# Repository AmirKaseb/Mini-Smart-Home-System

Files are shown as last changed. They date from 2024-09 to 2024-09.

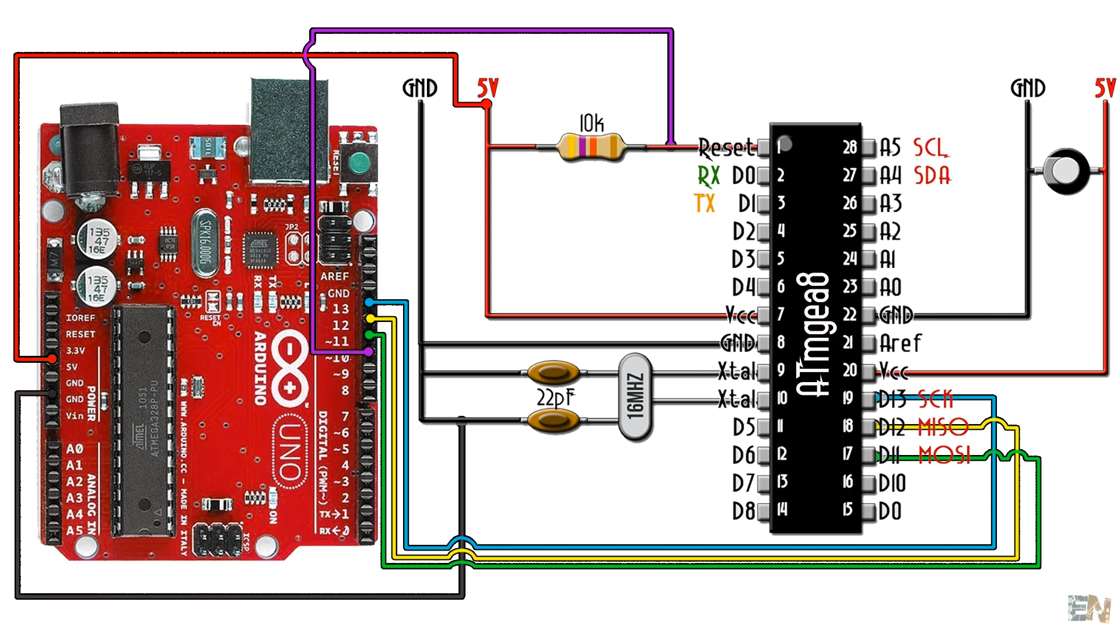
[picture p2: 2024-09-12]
Microcontroller & Hardware/Circuits/Arduino as ISP Programmer.png

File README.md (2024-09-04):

Computer Vision Part :-
=========================================================

This Part demonstrates real-time face recognition using OpenCV (`cv2`) and the `face_recognition` library in Python. The script captures video from the webcam, processes each frame to detect and recognize faces, and then displays the video with rectangles drawn around the recognized faces.

Requirements
------------

To install the required packages, run:

    cd /Computervision
    pip install -r requirements.txt

How to Use
----------

1.  **Place a Known Face Image:**
    *   Place an image file of the person you want to recognize (e.g., `amir.png`) in the same directory as the script.
2.  **Run the Script:**
    *   Use the following command to run the script:
    ````
        python face_recognition.py
    ````
3.  **How It Works:**
    *   The script will:
        *   Capture video from the default webcam.
        *   Load a known face from the provided image (`amir.png`).
        *   Detect faces in each video frame.
        *   Compare detected faces with the known face encoding.
        *   Draw a rectangle around recognized faces and display the name.
        *   Print a `Face Detected` flag to the console (`1` if a face is recognized, `0` otherwise).
4.  **Stop the Script:**
    *   Press the `q` key to stop the video capture and close all windows.

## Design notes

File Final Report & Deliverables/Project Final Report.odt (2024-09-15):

TEAM 11

Computer Vision Section:

Features:
- Beautiful and clear GUI implementation
- Clear and easy to use home layout that shows video, open door, lock door, add, delete and reset password buttons
- Dropdown menu for deleting persons from database instead of text field which is more convenient
- Confirmation dislogs for: open door, lock door, delete and reset password which gives homeowner a chance to think desicion through
- Notifications for carried out/cancelled activities which is convenient and less confusing for homeowner
- Most activities carried out using keys in the terminal, this allows running to be a lot smoother

Design considerations:
- Adding a person is a very simple process of snapping a picture of unknown person and creating a file with the persons image under the name of the person provided by the homeowner. This makes deleting a person exceptionally easy as all that needs to be done is delete the file's path obtained by joing the database path and the person's name.
- GUI is implemented using Flet which makes it easier to turn the program into a mobile app
-

Micro-controllers Section:

Features:

- Home Protection: When the house is locked, the PIR Sensor scans for motion and if detected, the ATmega sends a warning message to the Control Interface.
- Dynamic Lighting: When the light level of the surrounding is low, the Photo-resistor detects the low light and the ATmega lights up an LED and vice versa.
- Dynamic Fan Speed/RGB Indicator: According to the following ranges of temperature picked up by the NTC Thermo Sensor, the RGB – Fan Speed are as follow:
  ∗T > 30◦C : Red – 3500 RPM
  ∗ 30◦C => T => 20◦C: Green – [3000, 2000] RPM
  ∗ T < 20◦C: Blue – Fan Off
- Entering/Exiting House: A person can enter the house by:
  1- Entering the correct password on a 4*4 keypad
  2- By scanning their face (if a person is in the database, the Control Interface sends an open command to the ATmega)
  3- Pressing open on the Control Interface.
  A person can also lock the house via the Control Interface, turning off all the lighting and fan, and enabling the PIR Sensor to sends warning upon motion detection. The house/system is unlocked if the door is opened by any means of the 3.
- Door Password: A person can enter the house using a password and can change the password via the Control Interface. The password can have a length up to 31 characters. If a wrong password is entered, a Buzz is played and a warning message is sent to the Control Interface.

Libraries used:

- <Keypad.h>: For the keypad

Design considerations:

- If the door is opened, that means: the servo motor rotates up to a certain degree, waits for about 7 seconds and then closes.
- Added a “lock” feature, explained in the previous section.
- The fans always spin in 1 direction, therefore, the direction (in1 and in2) pins of the driver are connected directly to 5V and GND instead of the ATmega.

Other relevant information:

- The ATmega chip is programmed for the first time using an Arduino as ISP Programmer to burn the bootloader and/or upload the code.
- A USB to TTL (Serial) was used for the communication between the ATmega and the Control Interface (Computer), can also be used for uploading code after burning a bootloader first.

Hardware Section:

Altium:

Schematic:

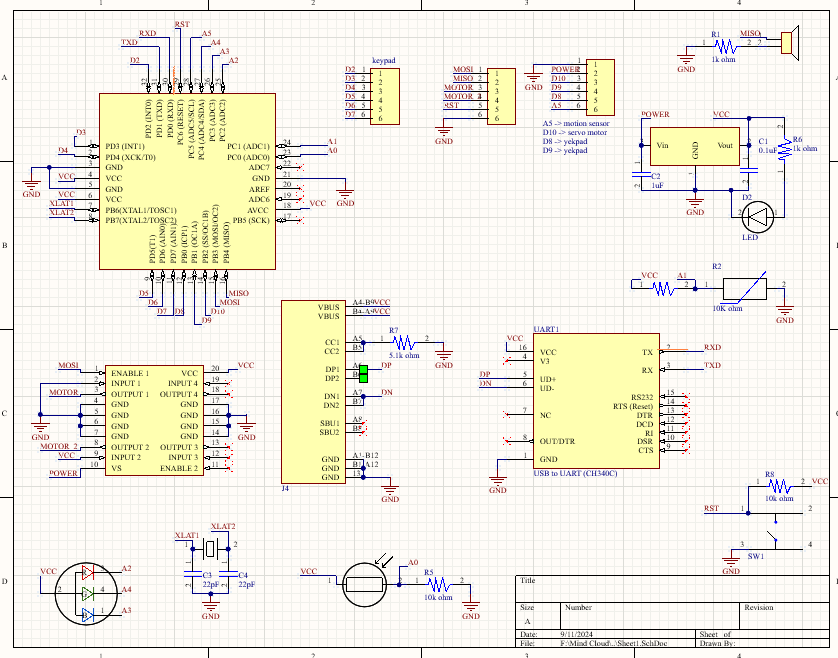
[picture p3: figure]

PCB-Top:

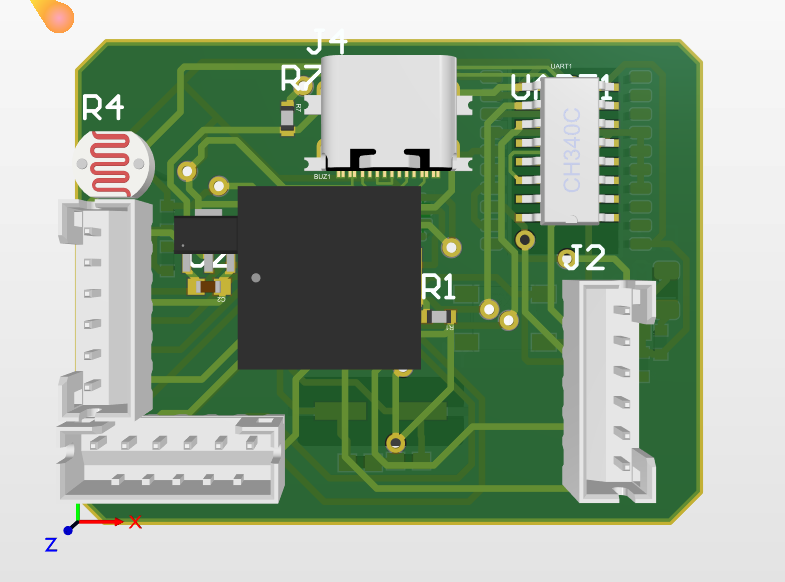
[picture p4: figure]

PCB-Bottom:

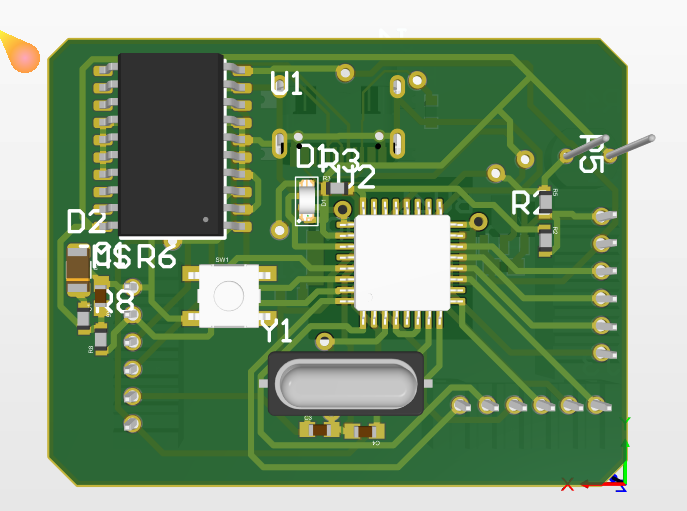
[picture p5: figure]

PCB-Traces:

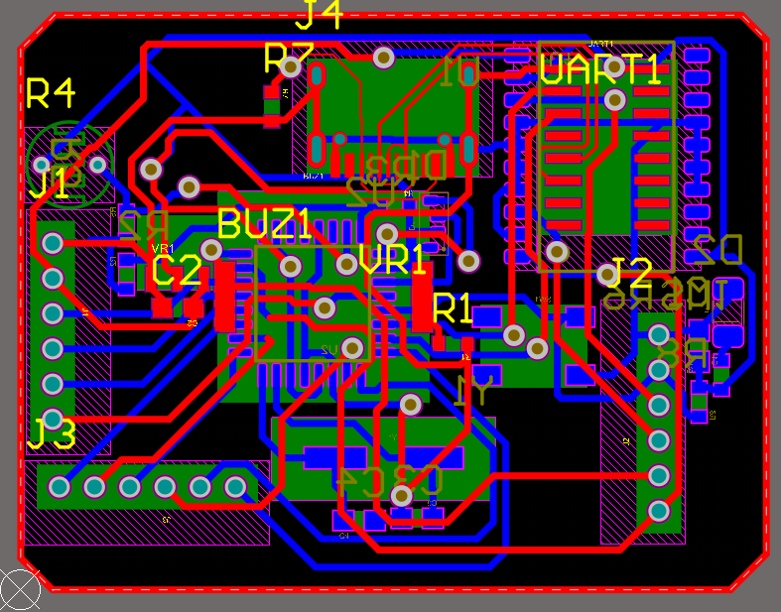
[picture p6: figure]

Design considerations:

- The servo motor, the fans motor and the keypad are not included in the Altium design, instead, they have pin-headers to connect them to the board externally.
- There are 6 Pins needed to exist as pin-headers to be able to program the ATmega chip (Burn the bootloader). The 6 pins are (MOSI – MISO – SCK – VCC – GND – Reset).
- We’re using a USB-to-UART chip and USB-C port for the communication of the ATmega and Computer.

Links:

AmirKaseb/Mini-Smart-Home-System: This Repo demonstrates our journey ( Team 11 ) for Mind Cloud Final Project (github.com) (https://github.com/AmirKaseb/Mini-Smart-Home-System/tree/main)

https://www.tinkercad.com/things/emIDLEaHkLq-mindcloud-megaproject-microcontroller-team-11

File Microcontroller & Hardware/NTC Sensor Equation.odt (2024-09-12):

NTC Thermistor Linearization

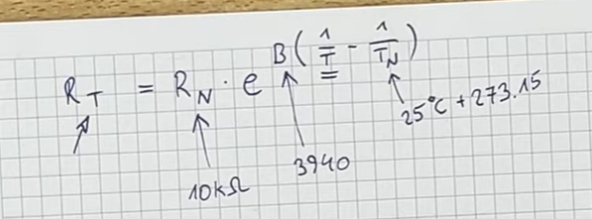
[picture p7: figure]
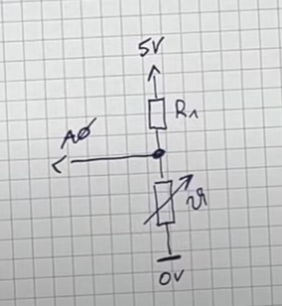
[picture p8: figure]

void loop(){

delay(1000);

double v_ntc = 5.0/1023 * analogRead(A0);

double current = (5.0-v_ntc)/10000.0;

double r_ntc = v_ntc/current;

double temp = 1 / ( log(r_ntc/10000.0)/3950 + 1/(25.0+273.15) ) -273.15;

}

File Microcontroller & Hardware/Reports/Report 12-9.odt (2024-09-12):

Days 9/9, 10/9, 11/9, 12/9

Computer Vision Section – Amir, Logy

Accomplishments:
Got started on gui and adding extra functions to the program

Problems encountered:
Choosing the most suitable gui to work with

Steps:
Read about different gui and comparing them according to activity, popularity and suitability.

Micro-controllers Section: - Badr

No new progress

Problems:

None

Hardware Section: - Mohammad Negm

- Mohammad worked and designed the whole system Schematic and PCB, the PCB is 2-sided to make it smaller.

- To consider: the 2 motors and the keypad are not in the design, instead, they’ve been allocated pinheaders to be connected externally, as it makes more sense this way.

Problems:

None

On 12/9, we’ve bought the necessary components, assembled and tested most of the system. Still CV to be tested.

Links:

AmirKaseb/Mini-Smart-Home-System: This Repo demonstrates our journey ( Team 11 ) for Mind Cloud Final Project (github.com) (https://github.com/AmirKaseb/Mini-Smart-Home-System/tree/main)

https://www.tinkercad.com/things/emIDLEaHkLq-mindcloud-megaproject-microcontroller-team-11

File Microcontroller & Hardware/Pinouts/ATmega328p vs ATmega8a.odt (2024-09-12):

Microcontroller – CV RELATION:

If the face recognized → open the door

Change password → change the password on the ardunio

Microcontroller: TinkerCad’s ATMEGA328P

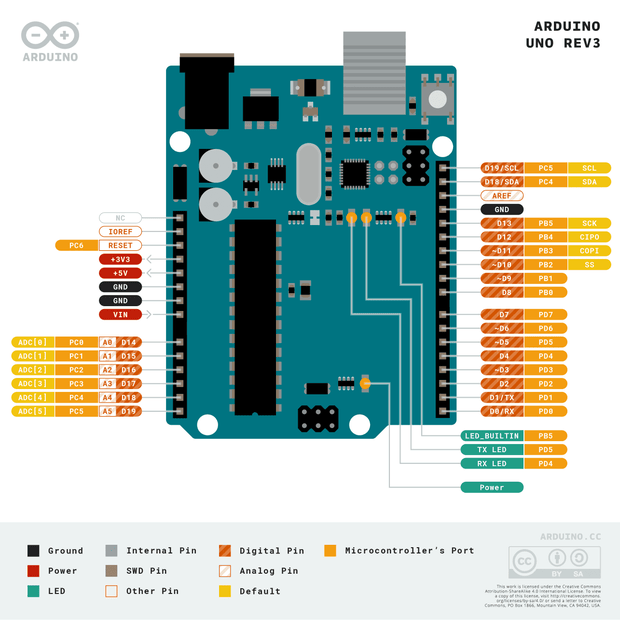
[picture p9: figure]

ATMEGA328P PDIP

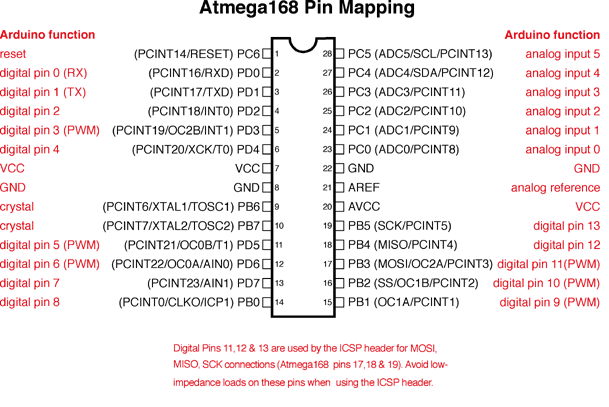
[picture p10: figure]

ATMEGA 8A PDIP

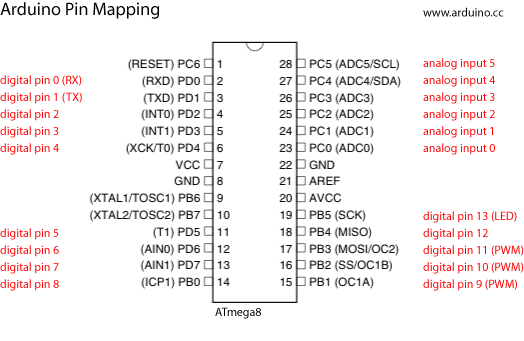
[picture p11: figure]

ATMEGA328P

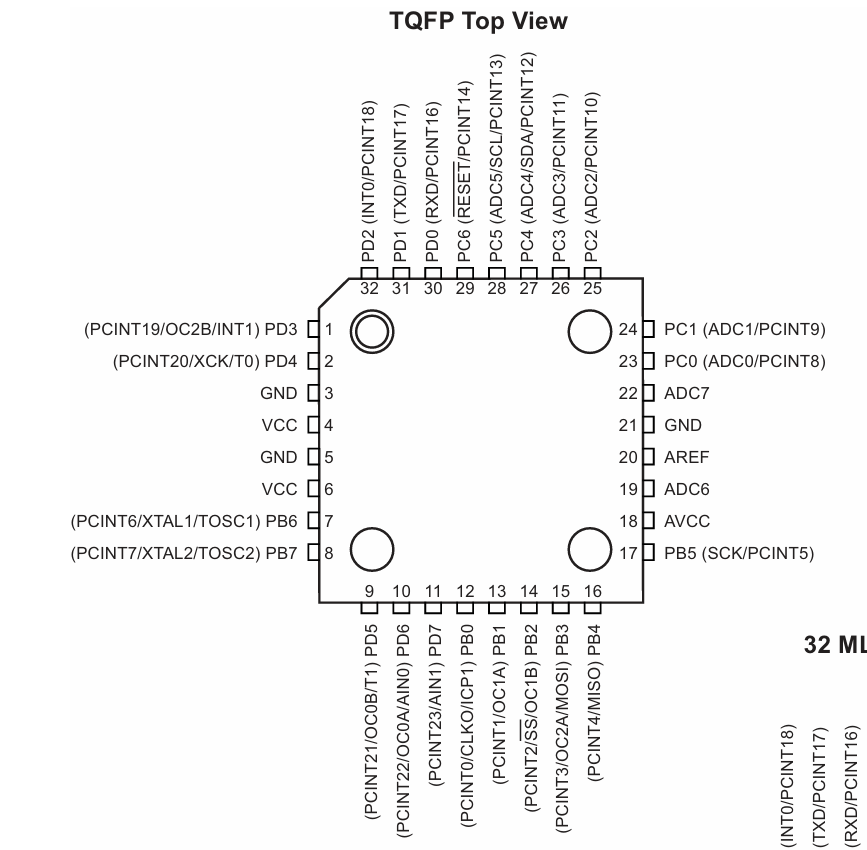
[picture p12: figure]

ATMEGA 8A

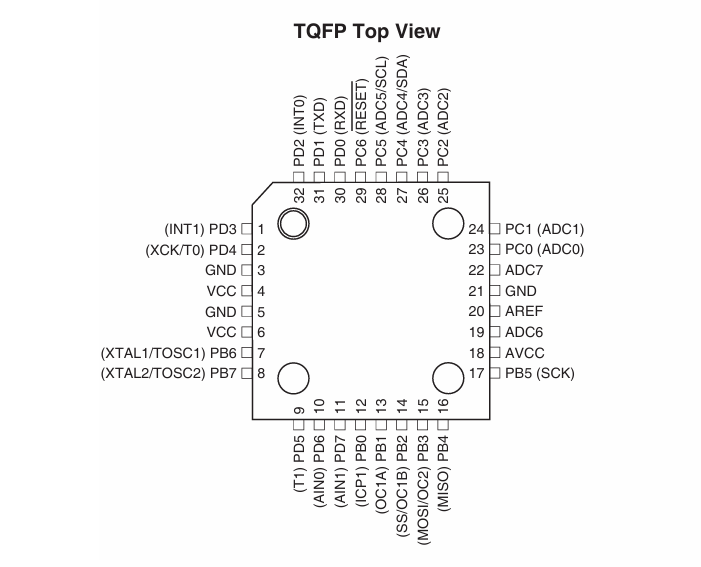
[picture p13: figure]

-ATMEGA328P Has 6 PWM channels while ATMEGA 8A only has 3 PWM channels

-Both has 6 ADC channels on PDIP package.

Components Links (Makers Store)

• Keypad : KeyPad 4×4 | Makers Electronics (https://makerselectronics.com/product/keypad-4x4)

• Buzzers : Magnetic Buzzer 5V 12mm 2 Pin | Makers Electronics (https://makerselectronics.com/product/magnetic-buzzer-5v-12mm-2-pin)

• Temperature sensor [NTC Thermistor Module] : NTC Thermistor 10KΩ | Makers Electronics (https://makerselectronics.com/product/ntc-thermistor-10kω)

• PIR sensor : PIR Sensor SR501 | Makers Electronics (https://makerselectronics.com/product/pir-sensor-sr501)

• LDR sensor : Photo Resistor Sensor LDR 7mm GL7528 8kΩ~20kΩ P=5mm | Makers Electronics (https://makerselectronics.com/product/photo-resistor-sensor-ldr-7mm-gl7528-8kω20kω-p5mm)

• RGB LED ; RGB Clear LED Common Cathode 5mm | Makers Electronics (https://makerselectronics.com/product/rgb-clear-led-common-cathode-5mm)

• Motor + Fan Blades : DC Motor R280 3-12V 13750RPM | Makers Electronics (https://makerselectronics.com/product/dc-motor-r280-3-12v-13750rpm) , Plastic Propeller 4 Blades 100mm | Makers Electronics (https://makerselectronics.com/product/plastic-propeller-4-blades-100mm)

• Driver L293D : L293D Quadruple Half-H Driver DIP-16 | Makers Electronics (https://makerselectronics.com/product/l293d-quadruple-half-h-driver-dip-16)

• LED (as lighting system) : Oval Red LED 3.8x5mm | Makers Electronics (https://makerselectronics.com/product/oval-red-led-3-8x5mm)

• Servo motor : Micro Servo SG90 0:180 Degree | Makers Electronics (https://makerselectronics.com/product/micro-servo-sg90-0180-degree)

Arduino

• ATMEGA 8A : ATMEGA8A-PU 8KB 2.7V~5.5V AVR 1KB 16MHz FLASH 23 DIP-28 AVR Microcontroller Unit | Makers Electronics (https://makerselectronics.com/product/atmega8a-pu-8kb-2-7v5-5v-avr-1kb-16mhz-flash-23-dip-28-avr-microcontroller-unit)

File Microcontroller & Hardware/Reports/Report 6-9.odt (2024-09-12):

Days 4/9, 5/9

Computer Vision Section – Amir, Logy

Accomplishments:
AI model that recognizes faces, successfully categorizes them into known and unknown by going through pictures of all known persons' faces in a database

Problems encountered:
None so far

Steps:
1. Training a model that recognizes faces using mainly face_recognition library, drawing frames around the face notifying the webcam's user whether they've been recognized or not
2. Writing a function that iterates over all pictures saved to a database to load images of known persons for the model to work with
3. Writing a function to extract names of persons from image's path for general ease (rather than turning to hard coding)
4. Work is readily uploaded to GitHub for ease of communication with teammates

Micro-controllers Section: - Badr

Looked into the specs and datasheet of the ATmega8A, found out that:

1- It’s a lower profile chip compared to the ATmega328P, with smaller memory and storage size. So, I have to keep the program size/memory consumption in consideration.

2- It has 3 PWM channels/pins and 6/8 ADC channels, depending on the package.

3- Has the same pinout as the ATmega328P on the Arduino Uno, so simulation on Tinkercad was somewhat possible and easy.

Learned how to work with the new stuff first, the Photoresistor, the NTC Sensor and the 4*4 Keypad, understood how they work and how to code for them.

Looked for real parts to be able to confirm the compatibility of my code.

Coded and simulated most -if not all- of the functions of the system. The communication between the Atmega and the Control Interface on the laptop can’t be tested virtually, so I used the Serial Monitor as input/output, such functions that are completed are as follow:

- If the door is opened (using password on keypad or serial input): Start the system

functions and unlock the house (PIR won’t try to detect if an intruder is present if the door is opened).

- Measure surrounding lighting level with LDR (control light system level) and if the reading from the LDR is low, meaning low light in the environment, turn the LED on, else, turn it off.

- Measure temperature with a temperature sensor and depending on that reading the result is

shown on RGB LED as follows:

∗ Red: T > 30◦C

∗ Green: 30◦C > T > 20◦C

∗ Blue: T < 20◦C

- The temperature sensor reading controls the speed of the motor with a fan extension with the

aid of an L293D chip, it has 3 modes, if T<20c then the fan is off, between 20c and 30c the fan is dynamic between 2000RPM and 3000RPM, and T > 30c the fan speed is constant at 3500RPM.

- Use a PIR sensor to detect if there is anyone inside the home if the door is locked and print on the serial monitor that there’s an intruder (only if the house is locked).

• If a WRONG password is entered:

- Buzzer rings for 500ms.

- Show warning messages on the serial monitor.

- Abilty to lock the system again via a serial monitor input, to shutdown the system (fan, lights and sensors) and the PIR sensor will begin working.

Problems:

1- Wrote the code for the NTC temp sensor but couldn’t test it as the temp sensor on Tinkercad is different, so right now, I use hardcoded values to simulate the values of the pin of the NTC temp sensor. It has no solution right now, only we wait til we build the project and see if it correctly works.

2- Instead of using 3 pins of the ATmega for the motor driver, I only used the Enable pin on the driver to control the speed (I can set it to 0 if I want the fan to stop), and the Input1-Input2 pins of the driver are always GND-5V, so the fan always spins in 1 direction (makes sense anyways).

3- Now, I’m going to optimize the code to be more memory efficient.

Hardware Section:

Work only started 6/9.

Links:

AmirKaseb/Mini-Smart-Home-System: This Repo demonstrates our journey ( Team 11 ) for Mind Cloud Final Project (github.com) (https://github.com/AmirKaseb/Mini-Smart-Home-System/tree/main)

https://www.tinkercad.com/things/emIDLEaHkLq-mindcloud-megaproject-microcontroller-team-11

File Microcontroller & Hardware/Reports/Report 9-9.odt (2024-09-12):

Days 6/9, 7/9, 8/9

Computer Vision Section – Amir, Logy

Accomplishments:
Code now successfully deletes known persons from database when prompted, opens the door when prompted and saves an unknown person to directory

Problems encountered:
Not adjusting to changes in directory after person has been added/removed
Unknown person's image being captured and saved with the frame still on their face

Steps:
1. Created a function to delete a person by deleting image's path from directory
2. Assigned keys for delete, reset password, add person, open door allowing homeowner to do so anytime
3. Capture a picture of person before adding the frame for picture to be saved without it
4. Reload all images in directory after adding/removing a person to stay up to date

Micro-controllers Section: - Badr

- Finished everything.

- Optimized a bit. I was using string type data for taking input from the serial channel (the control interface), but it was taking a lot of memory, so I switched to an array of char with fixed size as the buffer.

Problems:

None

Hardware Section: - Noran. Badr

-We started working on the libraries of the components (sch and footprint), and finished most of the components (only 4 components remaining, should be finished on 9/9).

Problems:

None

Links:

AmirKaseb/Mini-Smart-Home-System: This Repo demonstrates our journey ( Team 11 ) for Mind Cloud Final Project (github.com) (https://github.com/AmirKaseb/Mini-Smart-Home-System/tree/main)

https://www.tinkercad.com/things/emIDLEaHkLq-mindcloud-megaproject-microcontroller-team-11

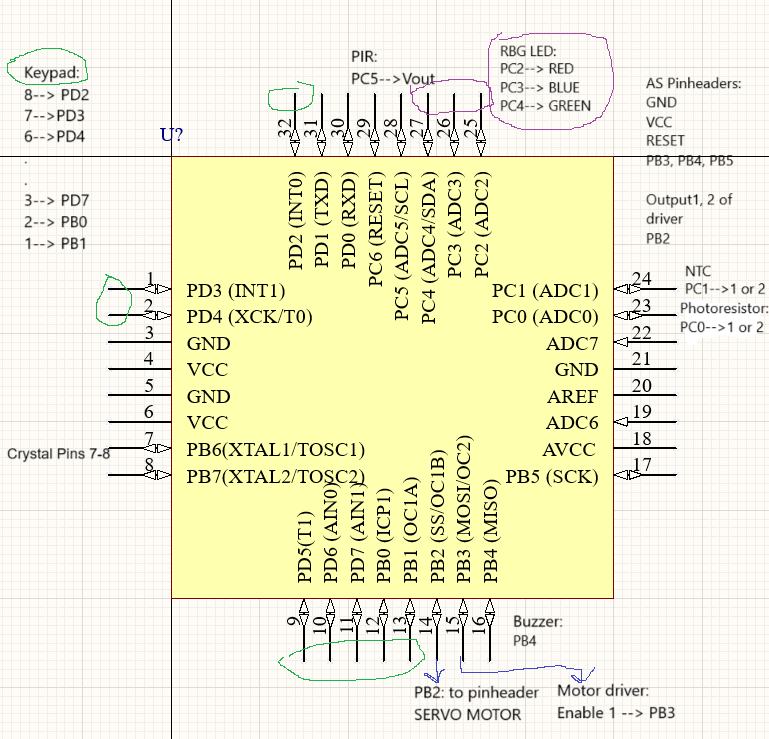
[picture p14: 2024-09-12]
Microcontroller & Hardware/Pinouts/ATmega8 TQFP Arduino-Pinout.png

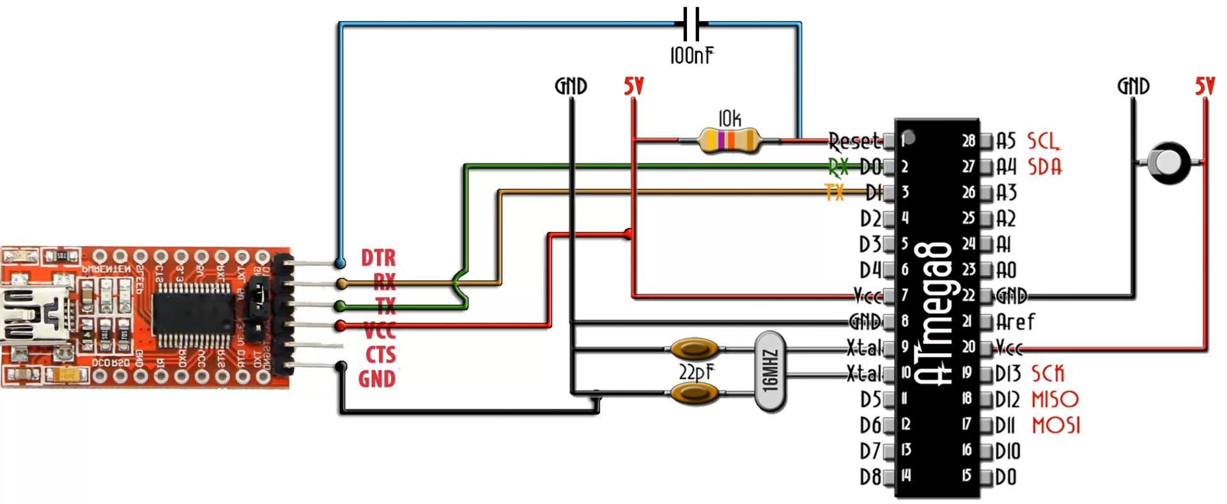
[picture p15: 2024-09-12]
Microcontroller & Hardware/Circuits/USB to TTL (Serial).png

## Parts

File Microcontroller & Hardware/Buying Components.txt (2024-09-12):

ATMEGA8A-PU 8KB 2.7V~5.5V AVR 1KB 16MHz FLASH 23 DIP-28 AVR Microcontroller Unit
KeyPad 4×4
Magnetic Buzzer 5V 12mm 2 Pin
NTC Thermistor 10K ±5% 3950K P=1.7mm (MF52A103J3950)
PIR Sensor SR501
Photo Resistor Sensor LDR 7mm GL7528 8kΩ~20kΩ P=5mm
RGB Clear LED Common Cathode 5mm
DC Motor R280 3-12V 13750RPM
Plastic Propeller 4 Blades 100mm
L293D Quadruple Half-H Driver DIP-16
Oval Red LED 3.8x5mm
Micro Servo SG90 0:180 Degree

Battery (9V?)

Resistors (220 - 1k - 10k - 5.1K)
Capacitors (22pF - 0.1uF - 1uF - 4.7uF - [10uF Electrolytic])

Crystal 16.000MHz
Push Button 4 pins and 2 pins

USB / UART : CH9102 Chip USB to TTL (Serial) Converter

Jumpers (Wires)

2 breadboards

Avometer

Arduino

~(Voltage Regulator - Diode)

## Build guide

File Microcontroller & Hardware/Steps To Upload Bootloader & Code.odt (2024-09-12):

Here's how you can set up your ATmega8A with a bootloader and then use it to upload code multiple times without needing an external Arduino:

### Step 1: Burn the Bootloader Using an External Arduino

1. **Set Up the Arduino as ISP**:

- Connect an Arduino (e.g., Arduino Uno) to your computer.

- Open the Arduino IDE.

- Load the "ArduinoISP" sketch from the examples (`File > Examples > ArduinoISP`).

- Upload this sketch to the Arduino. This turns the Arduino into an In-System Programmer (ISP).

2. **Connect the Arduino ISP to the ATmega8A**:

- Connect the Arduino to the ATmega8A as follows:

- **Arduino Pin 10** → **ATmega8A RESET (Pin 1)**

- **Arduino Pin 11** → **ATmega8A MOSI (Pin 17)**

- **Arduino Pin 12** → **ATmega8A MISO (Pin 18)**

- **Arduino Pin 13** → **ATmega8A SCK (Pin 19)**

- **Arduino GND** → **ATmega8A GND (Pin 8 or 22)**

- **Arduino 5V** → **ATmega8A VCC (Pin 7 or 20)**

3. **Burn the Bootloader**:

- In the Arduino IDE, go to `Tools > Board` and select "ATmega8" (with MiniCore installed, you'll see ATmega8 options).

- Set the clock frequency and other options according to your setup.

- In `Tools > Programmer`, select "Arduino as ISP."

- Click `Tools > Burn Bootloader`. This uploads the bootloader to your ATmega8A, making it ready for serial programming via the USB-to-TTL adapter.

### Step 2: Upload Code via USB-to-TTL Adapter

1. **Connect the USB-to-TTL Adapter**:

- Connect your USB-to-TTL adapter to the ATmega8A:

- **TX of the adapter** → **RX of the ATmega8A (Pin 2)**

- **RX of the adapter** → **TX of the ATmega8A (Pin 3)**

- **GND of the adapter** → **GND of the ATmega8A (Pin 8 or 22)**

- **VCC of the adapter** → **VCC of the ATmega8A (Pin 7 or 20)**

- **DTR or RTS of the adapter** (if available) → **RESET of the ATmega8A (Pin 1)** (through a 100nF capacitor).

2. **Upload Code**:

- Open the Arduino IDE.

- Write or open your code (sketch).

- Select the appropriate board (ATmega8 with the correct clock settings).

- In `Tools > Port`, select the COM port associated with your USB-to-TTL adapter.

- Click `Upload`. The bootloader will handle the process, allowing your code to be uploaded to the ATmega8A.

### Step 3: Repeat Code Uploads

- Now, each time you want to upload new code, you can directly use the USB-to-TTL adapter. The bootloader on the ATmega8A will automatically handle the code upload process, and there's no need to use the external Arduino again.

This setup allows you to easily and repeatedly upload code to your ATmega8A, making the development process more efficient.

If your USB-to-TTL adapter doesn’t have a DTR (Data Terminal Ready) pin, you can manually reset the ATmega8A to trigger the bootloader when uploading code. Here’s how you can do it using a button:

### Step 1: Wire the Button for Manual Reset

1. **Connect the Reset Pin**:

- Connect one leg of your push button to the **RESET** pin of the ATmega8A (Pin 1).

- Connect the other leg of the button to **GND**.

2. **Pull-up Resistor**:

- Connect a 10kΩ resistor between the **RESET** pin (Pin 1) and **VCC** (Pin 7 or 20). This pull-up resistor keeps the microcontroller running normally when the button is not pressed.

### Step 2: Manual Reset During Code Upload

1. **Prepare to Upload Code**:

- Write or open your code (sketch) in the Arduino IDE.

- Select the correct board settings (ATmega8 with the appropriate clock and bootloader).

- Select the correct COM port for your USB-to-TTL adapter.

2. **Trigger the Bootloader**:

- Click the **Upload** button in the Arduino IDE.

- Immediately after clicking **Upload**, press and hold the reset button on your ATmega8A.

- Release the button just as you see the "Uploading..." message in the Arduino IDE. This manual reset puts the ATmega8A into bootloader mode, ready to receive the new code.

3. **Code Upload**:

- The code should upload successfully if the timing of the reset is correct.

### Step 3: Repeat the Process

- Each time you upload new code, you’ll need to manually reset the ATmega8A at the right moment to trigger the bootloader.

This manual reset method is a common workaround when your USB-to-TTL adapter lacks a DTR pin. It may take a few tries to get the timing just right, but it works reliably once you get the hang of it.

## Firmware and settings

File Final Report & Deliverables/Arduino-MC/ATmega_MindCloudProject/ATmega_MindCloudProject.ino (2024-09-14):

#include <Keypad.h>

#define BUZZ 12
#define LED 13
#define motionPin A5
#define servoPin 10
#define LDRPin A0
#define TempPin A1
  
#define LED_R A2
#define LED_G A4
#define LED_B A3

#define EN 11
bool doorOpen=0;
bool sysUnlock=0;
  
void setup(){
  
  pinMode(BUZZ, OUTPUT);
  pinMode(LED, OUTPUT);
  pinMode(motionPin, INPUT);
  pinMode(servoPin, OUTPUT);
  pinMode(LDRPin, INPUT);
  
  pinMode(LED_R, OUTPUT);
  pinMode(LED_G, OUTPUT);
  pinMode(LED_B, OUTPUT);

  pinMode(EN, OUTPUT);
  
  Serial.begin(9600);
}

//Door/

void openDoor(int start=0){
  for (int i=start; i<=200; i++){ //turn the servo motor
    analogWrite(servoPin, i);
    delay(10);
  }  
}

void closeDoor(int end=200){
  for (int i=end; i>=0; i--){ //turn the servo motor
    //if (digitalRead(motionPin) == HIGH) return i; //if the door needs to open while it's closing, return with the value to start at opening
    analogWrite(servoPin, i);
    delay(10);
  }
  
  //return 60;
}


//KEYPAD Initials//
const byte ROWS = 4;
const byte COLS = 4;
char keys[ROWS][COLS] = {
  {'1','2','3','A'},
  {'4','5','6','B'},
  {'7','8','9','C'},
  {'*','0','#','D'}
};

//byte rowPins[ROWS] = {2, 3, 4, 5}; //connect to the row pinouts of the keypad
//byte colPins[COLS] = {6, 7, 8, 9}; //connect to the column pinouts of the keypad

byte rowPins[ROWS] = {9, 8, 7, 6}; //connect to the row pinouts of the keypad
byte colPins[COLS] = {5, 4, 3, 2}; //connect to the column pinouts of the keypad

Keypad keypad = Keypad( makeKeymap(keys), rowPins, colPins, ROWS, COLS );
int PW_Len = 6;
const int maxPW_Len = 32;
char Data[maxPW_Len]; //The incoming input password
char Master[maxPW_Len] = "123A45"; //The already set password
byte data_count = 0;
//bool CorrectPW;
//bool ChangePW;
////

//LDR//

void ldr(){

  const int threshold = 500;
  int sensor = analogRead(LDRPin);
  if(sensor<threshold){ //low light
    digitalWrite(LED,HIGH);  //turn LED on
  }  
  else{
    digitalWrite(LED,LOW);  //turn LED off
  }
}

//TEMP//
//NOTE: The temp doesn't work because tinkercad doesn't have NTC sensors.
// The code below is for NTC Sensor (replace 500 with the comment line)

float temp;

void tempSense(){
  
  float v_ntc = 5.0/1023 * analogRead(TempPin); //* 500;//
  float current = (5.0-v_ntc)/10000.0;
  float r_ntc = v_ntc/current;
  temp = 1 / ( log(r_ntc/10000.0)/3950 + 1/(25.0+273.15)  ) -273.15;
  //temp=80;
  Serial.print("Temp: ");
  Serial.print(temp);
  Serial.print("\n");
  //delay(1500);
  
  
}

//RGB Light//

void setLED(char c){
  
  if (c=='G') digitalWrite(LED_G, HIGH); 
  else digitalWrite(LED_G, LOW);
  if (c=='B') digitalWrite(LED_B, HIGH); 
  else digitalWrite(LED_B, LOW);
  if (c=='R') digitalWrite(LED_R, HIGH); 
  else digitalWrite(LED_R, LOW);

}

void RGB(float temp1){
  if (temp1<20){
  	setLED('B');
  }
  else if (temp1>=20 && temp1<=30){
  	setLED('G');
  }
  else {
  	setLED('R');
  }

}

//Motor Fan//

void motor(float temp1){
  
  //DC Motor R280 3-12V 13750RPM
  //analogWrite(EN, 255);
   
  if (temp1<20){
  	analogWrite(EN, 0);
  }
  else if (temp1>=20 && temp1<=30){
    int RMPtoAnalog = (temp*100/13750.0)*255;
  	analogWrite(EN, RMPtoAnalog);
  }
  else {
    int RMPtoAnalog = (3500/13750.0)*255;
  	analogWrite(EN, RMPtoAnalog);
  }
}

//System Functions//
void openCloseDoor(){
  startSys();
      
  sysUnlock=1;
  doorOpen=1;
  openDoor();
  delay(7000);
  closeDoor();
  doorOpen=0;
}

void startSys(){
  ldr();
  tempSense();
  RGB(temp);
  motor(temp);
}

//KEYPAD//
void kp(){
  
  delay(70);
  char key = keypad.getKey();
  
  if (key){
    Serial.print(key);
  	Serial.print("\n");
    Data[data_count]=key;
    data_count++;
  } 
  
  if (data_count==PW_Len){
  
    if(!strcmp(Data, Master)){
      Serial.print("Correct Password\n");
      Serial.print("Opening Door\n");
      openCloseDoor();
      
      delay(1000);
      }
    else{
      //
      //SEND To Control Interface Too//
      //
      Serial.print("Incorrect Password\n");
      tone(BUZZ, 300, 500);
      
      delay(1000);
      }
  
  	//Clearing the data array
    data_count=0;
    for (int i=0; i<PW_Len; i++){
      Data[i]=0;
    }
  }
  

}


//Control Interface//

void ctrl(){

  if (Serial.available() > 0) {
    char msg[32] = "";
    int len = Serial.readBytes(msg, sizeof(msg) - 1); //msg buffer
    msg[len] = '\0'; 

    if (strcmp(msg, "open") == 0 && !doorOpen) {
      Serial.print("Opening Door\n");
      openCloseDoor();
      
    } 
    else if (strcmp(msg, "change") == 0) {
        delay(5000);
        if (Serial.available() > 0) {
            len = Serial.readBytes(msg, sizeof(msg) - 1); 
            msg[len] = '\0'; 
            
            if (strlen(msg) <30) {
              strcpy(Master, msg); //Copy new password to Master
              PW_Len = strlen(msg);  
              Serial.print("Password Changed!\n");
            }
          else {
            Serial.print("Password Too Long!\n");
          }
        }
    }

    else if (strcmp(msg, "lock")==0) {
      sysUnlock=0;
      digitalWrite(LED,LOW);
      analogWrite(EN, 0);
      setLED('0');
      Serial.print("System Locked!\n");
    }
  
  }
  
}


//LOOP//

void loop(){
  //sysUnlock=1;
  
  //KEYPAD//
  if (!doorOpen) kp();
  
  //Control Interface//
  ctrl();
  //Serial.write(Master);
  //Serial.write("\n");
  //delay(1000);
  
  //PIR//
  if (!sysUnlock){
  	byte motionStatus = digitalRead(motionPin);
    if (motionStatus){
      	//
      	//SEND To Control Interface Too//
      	//
    	Serial.print("WARNING: Intruder\n");		
    }
  }
  
  //Starting The System Functions//
  if (sysUnlock){
    
    startSys();
  
  }
}

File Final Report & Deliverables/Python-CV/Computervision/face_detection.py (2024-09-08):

import os
from pathlib import Path
import cv2
import face_recognition

###################################
# Functions to be used

# Draw rectangular frame around person's face
def draw(face_detected, frame, left, top, right, bottom, name):
    # Set color based on face detection status
    if face_detected:
        color = (0, 255, 0) # Green for recognized
    else:
        color = (0, 0, 255)  # Red for unrecognized

    # Draw rectangle around face
    cv2.rectangle(frame, (left, top), (right, bottom), color, 2)
    cv2.rectangle(frame, (left, bottom - 35), (right, bottom), color, cv2.FILLED)

    # Write name below face
    font = cv2.FONT_HERSHEY_DUPLEX
    cv2.putText(frame, name, (left + 6, bottom - 6), font, 0.5, (255, 255, 255), 1)

    return frame

# Extract the file name without the extension
def name_from_path(image_path):
    base_name = os.path.basename(image_path)
    name = os.path.splitext(base_name)[0]
    return name

def path_from_name(name, folder_path):
    path = r"C:\Users\Administrator\Desktop\Known"
    image_path = os.path.join(folder_path, f"{name}.png")
    return image_path
    
# Load all images in the directory
def load_image(folder_path):
    known_face_encodings = []
    known_face_names = []

    for image_path in folder_path.glob("*.png"):
        image = face_recognition.load_image_file(image_path)
        encodings = face_recognition.face_encodings(image)
        if encodings:
            known_face_encodings.append(encodings[0])
            known_face_names.append(name_from_path(image_path))

    return known_face_encodings, known_face_names

# Function to open the door
def homeowner_open(face_detected, door_opened, homeowner_ask, key):
    if not face_detected and not door_opened:
        if not homeowner_ask:
            print("Press 'o' to open the door")
            homeowner_ask = True # This ensures that the message is only printed only once

        if key == ord('o'):
            print("Door opened")
            door_opened = True
            print("Press 'a' to add person to database")

    return door_opened, homeowner_ask

# Function to add person to the database and reload images
def homeowner_add(door_opened, key, clean_frame, folder_path):
    if door_opened and key == ord('a'):
        name = input("Enter the person's name: ")
        cv2.imwrite(path_from_name(name, folder_path), clean_frame)
        print(f"Person added as {name}")

        return True
    return False
    
def delete_person(name, folder_path):
    image_path = path_from_name(name, folder_path)
    
    # Check if person's image exists
    if os.path.exists(image_path):
        # Delete the image
        os.remove(image_path) 
        return True
    
###################################

if __name__ == "__main__":
    # Initialize video capture
    cam = cv2.VideoCapture(0)
    if not cam.isOpened():
        print("Error: Could not open video capture")
        exit()

    folder_path = Path(r"C:\Users\Administrator\Desktop\Known")  # Default directory

    # Load known faces and their names from the specified directory
    known_face_encodings, known_face_names = load_image(folder_path)

    door_opened = False
    homeowner_ask = False

    while True:
        # Capture frame-by-frame
        ret, frame = cam.read()
        if not ret:
            print("Failed to grab frame")
            break

        # Create a clean copy of the frame before drawing in case image will be saved
        clean_frame = frame.copy()

        # Detect face locations and encodings in the current frame
        face_locations = face_recognition.face_locations(frame)
        face_encodings = face_recognition.face_encodings(frame, face_locations)

        face_detected = False
        name = "Unknown"

        # Compare detected faces with known faces
        for (top, right, bottom, left), face_encoding in zip(face_locations, face_encodings):
            matches = face_recognition.compare_faces(known_face_encodings, face_encoding)

            if True in matches:
                first_match_index = matches.index(True)
                name = known_face_names[first_match_index]
                face_detected = True

            # Draw a rectangle around the face
            frame = draw(face_detected, frame, left, top, right, bottom, name)

        # Display the resulting frame
        cv2.imshow('Video', frame)

        # Check for user key press
        key = cv2.waitKey(1) & 0xFF

        # Handle quitting and password reset functionality at any time
        if key == ord('q'):
            print("Quitting...")
            break  # Exit the loop

        if key == ord('r'):
            password = input("New password: ")
            print(f"Password updated to: {password}")
            
        if key == ord('d'):
            name = input("Enter name of person to delete: ")
            if (delete_person(name, folder_path)):
                known_face_encodings, known_face_names = load_image(folder_path)
                print(f"{name} deleted from database")
            else:
                print(f"{name} doesn't exist in database")
        # Handle homeowner decisions
        door_opened, homeowner_ask = homeowner_open(face_detected, door_opened, homeowner_ask, key)
        if homeowner_add(door_opened, key, clean_frame, folder_path):
            # Reload the known faces and names as a new person has been added
            known_face_encodings, known_face_names = load_image(folder_path)

            # Reset flags to go back to detecting faces
            door_opened = False
            homeowner_ask = False

    # Release the capture and close windows
    cam.release()
    cv2.destroyAllWindows()

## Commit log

2024-09-12 Microcontroller & Hardware Materials
    All the materials and resources of the work of the Microcontroller & Hardware sections.
2024-09-12 More Materials
2024-09-14 Final Report Stuff
    [PCB1.PcbDoc, PCBLibrary-Badr.PcbLib, PCBLibrary.PcbLib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]
2024-09-15 Our Final Fixed Fucking Version
    [face_detection_with_gui.py, serial_monitor.py]
